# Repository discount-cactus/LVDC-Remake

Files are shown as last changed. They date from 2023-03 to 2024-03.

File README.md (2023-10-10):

# LVDC-Remake
Goal: Build an equivalent of the flight computer to the Saturn V rocket from the 1960's.

From: October 9th, 2022 - Present

<em>DISCLAIMER: This repo does NOT include schematics, board layouts or fabrication files for any of the boards that make up the project. The purpose of this repo is to share a breif insight to the progress of the project. Some small pieces of the project are provided, but are merely for educational purposes.</em>

### Memory Element



The Memory Element is composed of the memory and circuitry that manages the memory structure itself and stores all data for the LVDC. The original memory element stored information in a 128x64x14 array of ferrite cores that were magnetized in a certain direction to store a 1 or 0. For this project, and due to the complexity of constructing such an array of tiny ferrite cores, an Arduino Mega Pro was used to emulate this array - which further led to several modifications to circuitry directly interacting with the would-be ferrite core array.

### Memory Control Element



The Memory Control Element acts as the bridge between the memory and the rest of the computer by taking in commands and other addressing signals to be sent to the memory element to read and write to/from the memory. During read instructions, the memory control element configures the memory element to be ready to be read from - and likewise during write instructions configures the memory element to be written to.

### Data Control Element



The Data control Element provides the main register responsible for transferring data to locations all over the computer.

### Program Control Element



The Program Control Element manages the starting and stopping of programs, conditioning memory address decoders to select instructions, selecting data and instruction memory sectors, selecting instruction addresses within memory sectors, storing and decoding op codes, interrupting programs to perform subroutines and generating HOP constants to resume programs. 

### Arithmetic Element / Multiply-Divide Element



The Arithmetic Element and the Multiply-Divide Element were combined into the same board given their similar functions. Together, they handle all mathematical computations on the computer. The arithmetic handles all addition and subtraction and similar operations while the multiply-divide element, given their complexity, are dedicated strictly to binary multiplication and division.

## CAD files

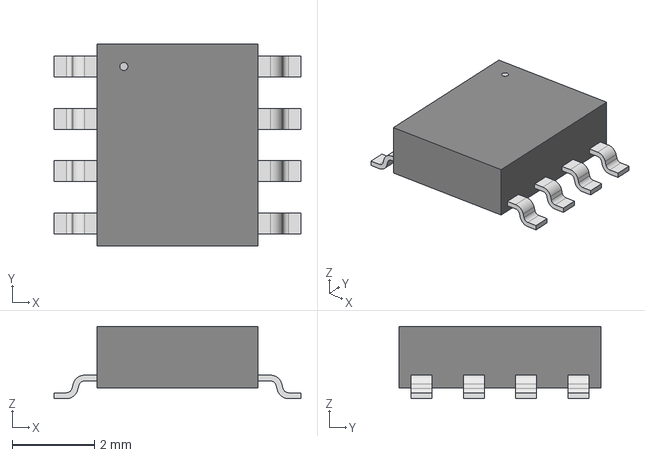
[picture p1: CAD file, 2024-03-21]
LVDC-Parts-Kicad/3dmodels/MCP2551_I_SN.step
5.99 x 4.90 x 1.75 mm

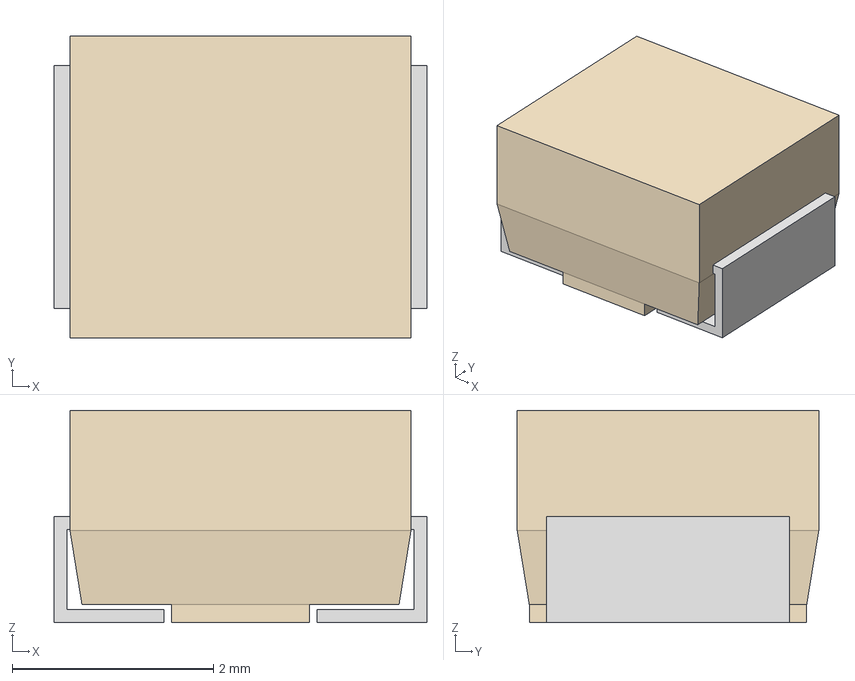
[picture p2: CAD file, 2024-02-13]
LVDC-Parts-Kicad/3dmodels/C_1411.step
3.71 x 3.00 x 2.11 mm

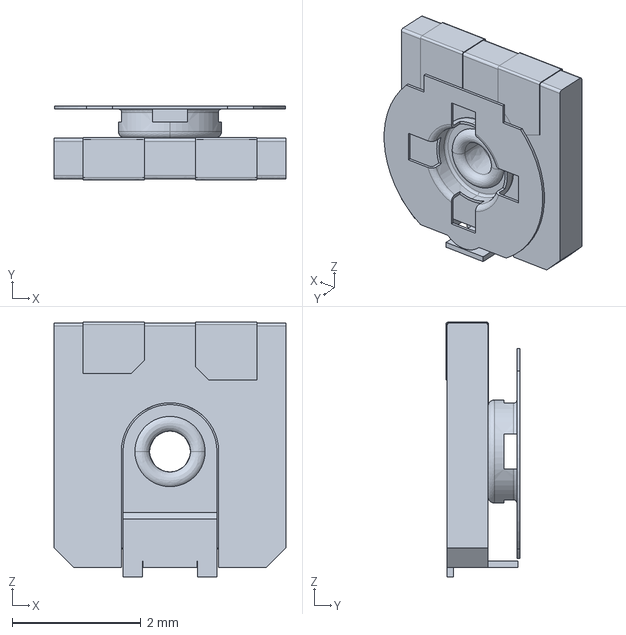
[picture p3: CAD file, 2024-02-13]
LVDC-Parts-Kicad/3dmodels/TC-33X-2.step
3.60 x 1.15 x 3.96 mm

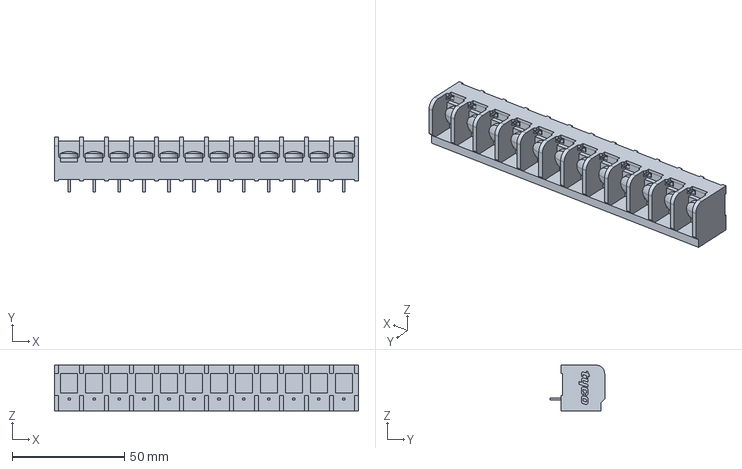
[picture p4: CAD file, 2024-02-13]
LVDC-Parts-Kicad/3dmodels/4-1437658-5.step
135.2 x 24.3 x 20.3 mm

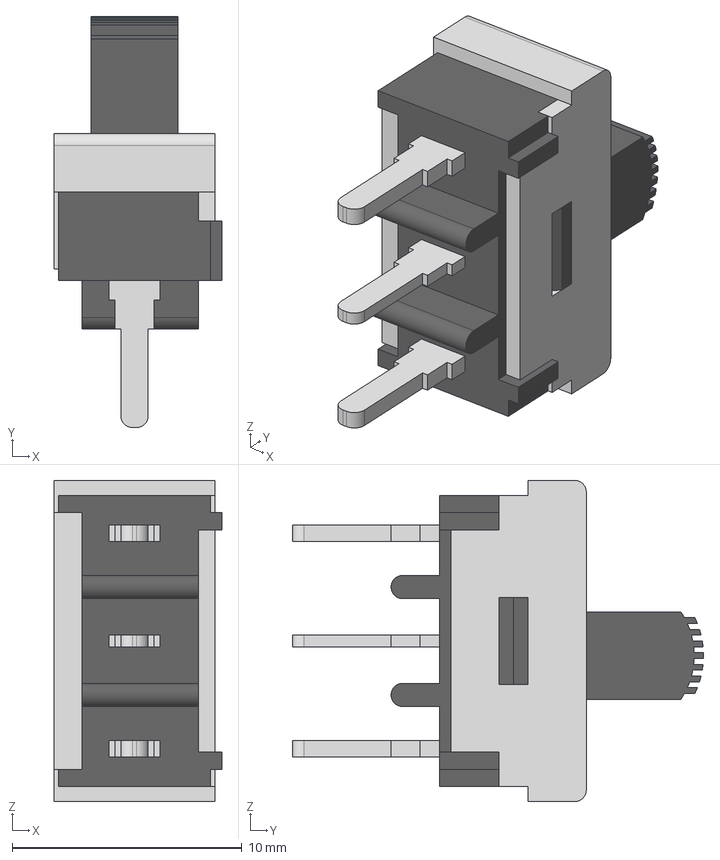
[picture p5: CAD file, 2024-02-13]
LVDC-Parts-Kicad/3dmodels/SPDT.step
7.32 x 17.9 x 14.0 mm
CS12ANW03-slide
CS12ANW03-term
CS12ANW03-top
CS12ANW03-body

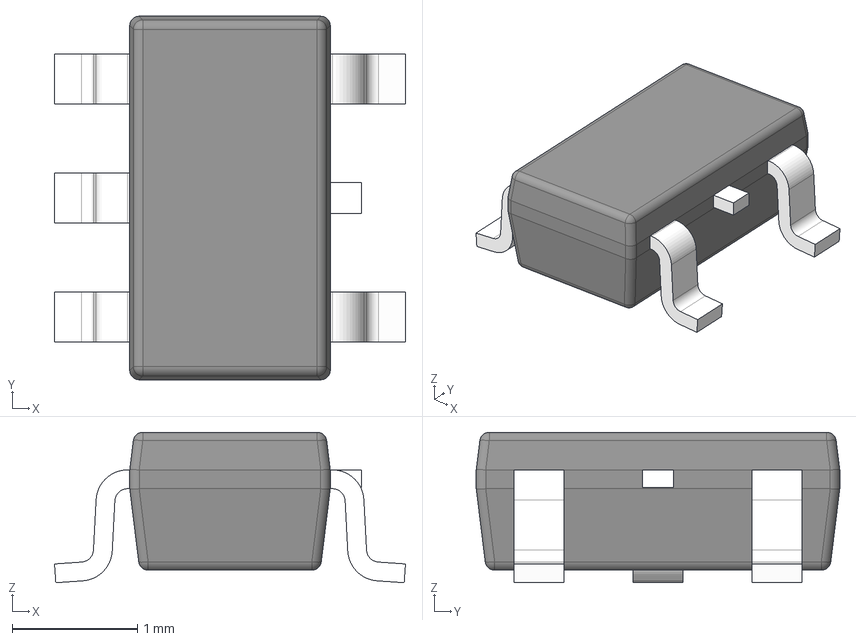
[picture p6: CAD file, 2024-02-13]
LVDC-Parts-Kicad/3dmodels/TLV170IDBVR.step
2.80 x 2.90 x 1.20 mm
BODY-SOT
LEAD-SOT x 5
LEAD-DUMMY

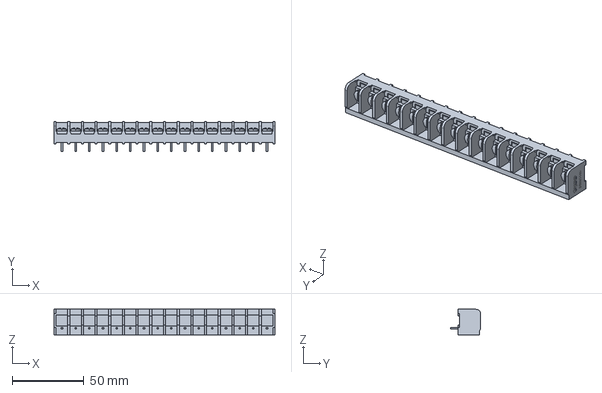
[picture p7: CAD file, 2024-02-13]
LVDC-Parts-Kicad/3dmodels/6PCV-16-006.step
153.9 x 21.0 x 17.8 mm

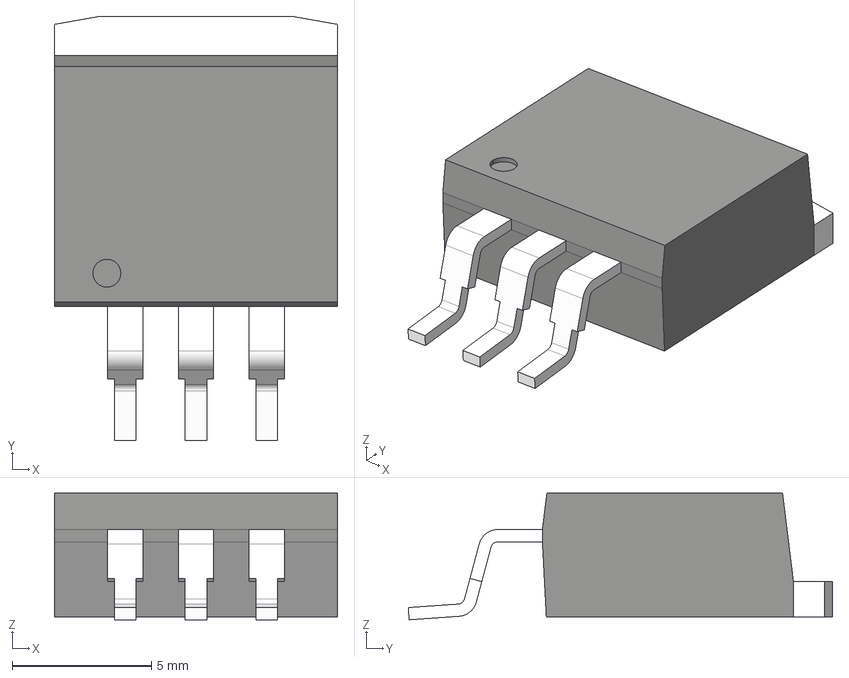
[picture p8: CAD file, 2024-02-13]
LVDC-Parts-Kicad/3dmodels/LM1084ISX-5-0-NOPB.step
10.2 x 15.2 x 4.54 mm
BODY-TO
HTSINK-TO263
LEAD-TO263 x 3

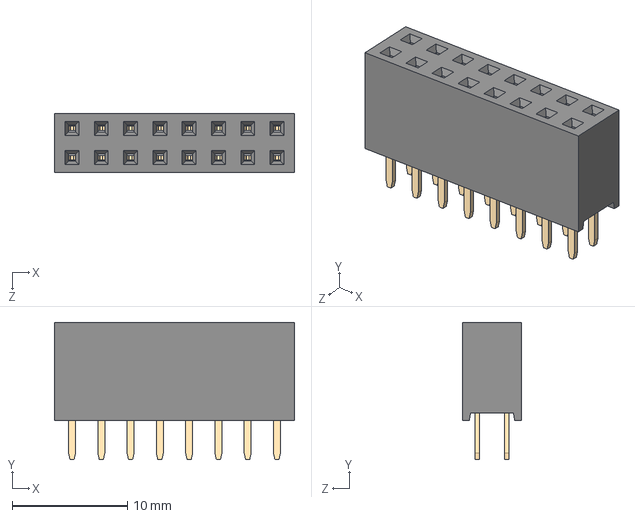
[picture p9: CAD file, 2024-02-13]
LVDC-Parts-Kicad/3dmodels/2x8.step
20.8 x 11.9 x 5.08 mm
2 row tin body_08
2 row tin pins x 8

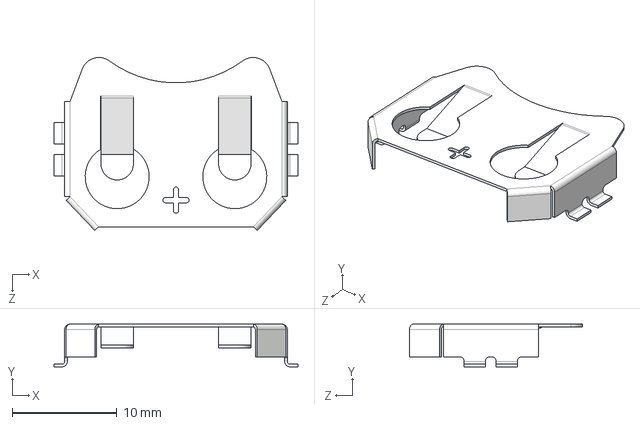
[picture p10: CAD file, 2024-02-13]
LVDC-Parts-Kicad/3dmodels/3034TR.step
23.2 x 4.06 x 16.5 mm

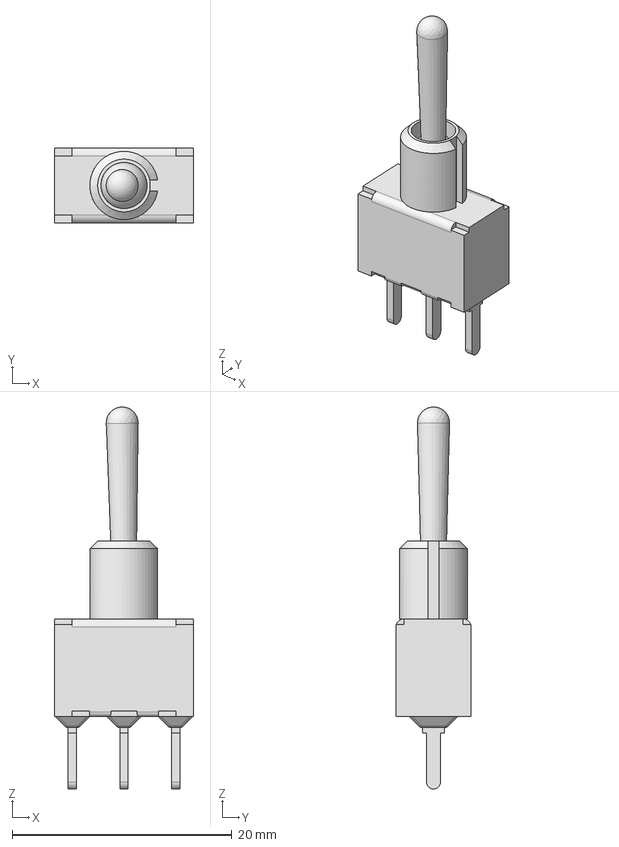
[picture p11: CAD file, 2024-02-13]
LVDC-Parts-Kicad/3dmodels/100SP1T1B4M2QE.step
12.7 x 6.86 x 34.8 mm

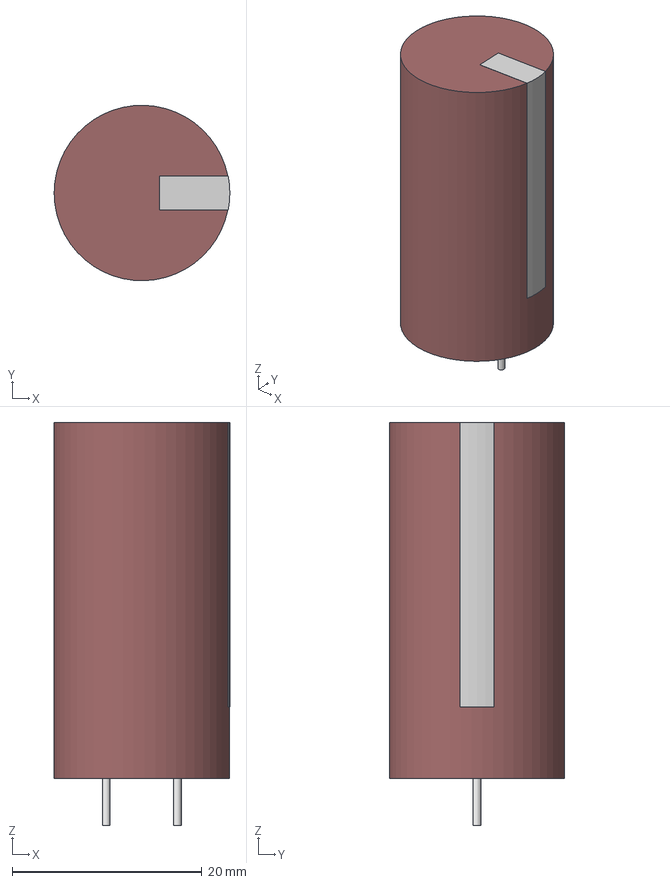
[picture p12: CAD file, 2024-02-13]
LVDC-Parts-Kicad/3dmodels/C_PKPZ.step
18.5 x 18.5 x 42.5 mm

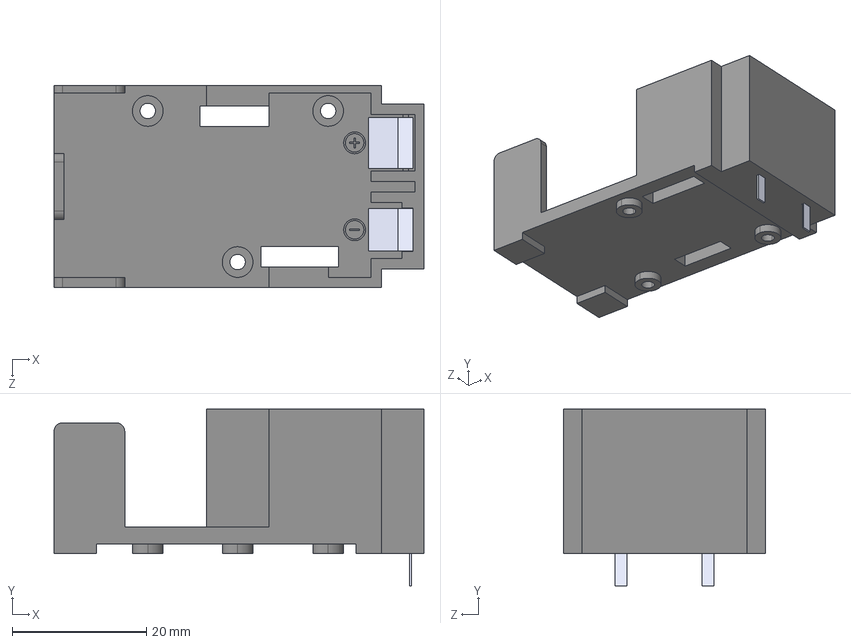
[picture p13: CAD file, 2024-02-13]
LVDC-Parts-Kicad/3dmodels/BC9VPC.step
55.1 x 26.3 x 30.1 mm

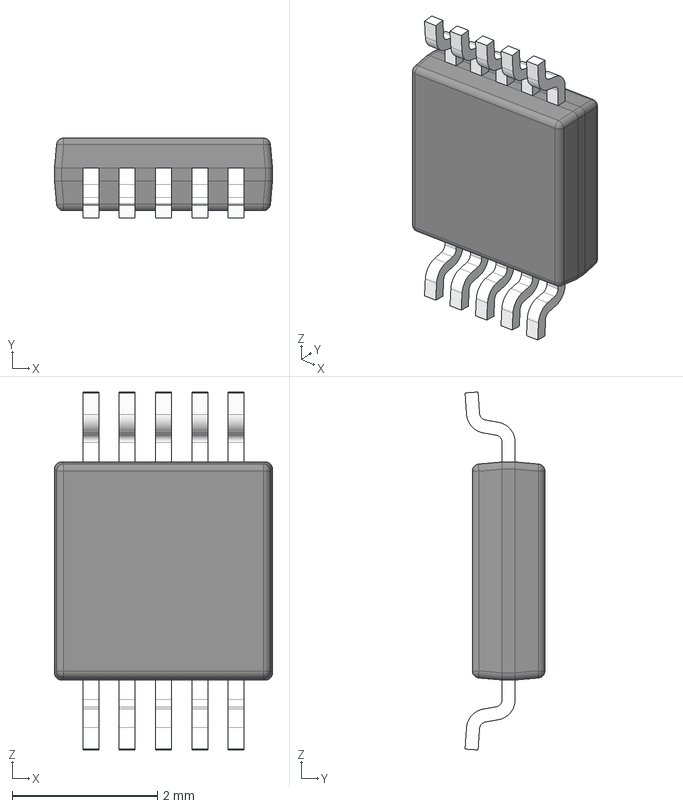
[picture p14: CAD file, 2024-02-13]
LVDC-Parts-Kicad/3dmodels/ADS1115IDGST.step
3.00 x 1.10 x 4.93 mm
BODY-SO
LEAD-SO x 10
PIN1-ID

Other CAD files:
LVDC-Parts-Kicad/3dmodels/LDL1117S50R.step
LVDC-Parts-Kicad/3dmodels/TS50P07G.step
LVDC-Parts-Kicad/3dmodels/DS3231M+TRL.step
LVDC-Parts-Kicad/3dmodels/1043P.step
LVDC-Parts-Kicad/3dmodels/10118193-0001LF.step
LVDC-Parts-Kicad/3dmodels/1017503.step
LVDC-Parts-Kicad/3dmodels/1101M2S3CQE2.step
LVDC-Parts-Kicad/3dmodels/14_DIP.step
LVDC-Parts-Kicad/3dmodels/16_DIP.step
LVDC-Parts-Kicad/3dmodels/1N4736A.step
LVDC-Parts-Kicad/3dmodels/1x10.step
LVDC-Parts-Kicad/3dmodels/1x13.igs
LVDC-Parts-Kicad/3dmodels/1x14.step
LVDC-Parts-Kicad/3dmodels/1x2.step
LVDC-Parts-Kicad/3dmodels/1x3.step
LVDC-Parts-Kicad/3dmodels/1x4.step
LVDC-Parts-Kicad/3dmodels/1x6.step
LVDC-Parts-Kicad/3dmodels/282858_4.step
LVDC-Parts-Kicad/3dmodels/2x12.step
LVDC-Parts-Kicad/3dmodels/2x13.step
LVDC-Parts-Kicad/3dmodels/2x14.step
LVDC-Parts-Kicad/3dmodels/2x16.STEP
LVDC-Parts-Kicad/3dmodels/2x18.step
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

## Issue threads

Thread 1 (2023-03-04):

Fix Input Interface Clocks

discount-cactus, 2023-03-04:
The input interface clocks were routed incorrectly during layout in Eagle and need to be reworked.

Actions:
- [x] Identify correct routing
- [x] Formulate plan to make all clocks functional with modifications to existing circuitry (_NOTE: 555 timers are in stock_)
- [x] Execute plan

discount-cactus, 2023-03-28:
Built replacement 555 timer that will be put onto the input interface tomorrow

discount-cactus, 2023-03-28:
The plan will be to remove clock circuitry and use the header pins on the input interface and will be bridged from the header pins to the perfboard with the replacement 555 timer.

discount-cactus, 2023-03-29:
Clock circuitry on input interface was removed to enable new clock circuitry to function. Incorrect wiring fried the 555 timer currently on the new 555 timer breakout board. The problem was fixed, leaving the only issue being the burnt 555 timer on the board. The plan now is to remove the burnt 555 timer, mount a new 555 timer on the opposite side, exposing the pins above, and jumping wires between the two 555 timers pins.

discount-cactus, 2023-03-30:
Finished the replacement timer circuit.

Closed 2023-03-30.

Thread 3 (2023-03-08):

Transistor Logic Trade Study

discount-cactus, 2023-03-08:
Test each type of single-stage amplifier and logic gate and log the results.

discount-cactus, 2023-04-20:
4/19/2023: After reviewing the task and ultimate goal of the study, the study is being moved to "Idea" indefinitely. The goal of the trade study was to understand the output voltage of transistor AND gates and OR gates but this is already known. The unknown was whether a resistor was NEEDED on the base for the circuit to work. The conclusion is "probably but maybe not" so (10kohm) resistors will be added to the base inputs of all transistor logic gates from now on to err on the side of caution.

discount-cactus, 2023-04-20:
Relevant pictures for optional future reference:
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

Closed 2023-04-22.

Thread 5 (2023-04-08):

Test Memory Module Stack

discount-cactus, 2023-04-08:
Use Timing Element R2

discount-cactus, 2023-04-13:
FRAM Chip Functionality.
- I2C connections are correct (4/9/2023)
- Adafruit uses 5V, Memory Modules use 3.3V. This should work as per Digikey website (4/9/2023)

https://learn.adafruit.com/adafruit-i2c-fram-breakout/wiring-and-test

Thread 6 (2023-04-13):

Input Interface Rev2

discount-cactus, 2023-04-13:
-Mechanical relays to physically cut power to 20V, 12V, 6V and 3V outputs
-Slow, medium, fast and manual clocks + 2 ports for external clocks
-Ports to gather data to send to python file
-Stiffener to prevent board warping
-Dock for espresso

discount-cactus, 2023-04-13:
4/12/2023:
Idea is as follows:
- Input Interface is a backplane with:
     - `Slots for five logic cards that plug in to the board, an onboard Arduino is used to select the logic cards`
     - `Slot for a single clock card to control the master clock`
     - `Plug-in for the Wall outlet-to-24V like on R1`
     - `Power is broken into 20V, 12V, 6V and 3V and distributed by distribution tiles - one for each board in the system and they stack vertically from the backplane like the memory module PCB's`
     - `Features a stiffener to prevent board warping like seen on R1`

discount-cactus, 2023-04-22:
4/21/2023:
- The input interface will feature two boards - an input/programming board and a power distribution board.
- Input Interface: Small board to mount up to five logic cards and a single clock card perpendicularly.
- Power Distribution: Built solely for distributing, managing and protecting the power going to each board that makes up the project.

discount-cactus, 2023-05-27:
5/26/2023: Issue closed due to decision on the architecture going forward.

Closed 2023-05-27.

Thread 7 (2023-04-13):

Latch Design Trade Study

discount-cactus, 2023-04-13:
The bistable storage latch on the LVDC project has been a persistent issue since the beginning so I am finally opening an issue specifically for tackling the design.

discount-cactus, 2023-04-13:
Design as of 3/30/23.

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

discount-cactus, 2023-04-13:
Schematic of latch per the NASA documentation:

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

discount-cactus, 2023-04-13:
Design as of 3/30/23:

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

discount-cactus, 2023-04-13:
Design as of 4/2/23:
The design was changed again and utilizes a CD4002BE quad 2-input OR gate to simplify the circuit from 12 components to 1.

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

discount-cactus, 2023-04-14:
4/13/2023: Initial testing was done with the design and the circuit looks promising, however the outputs are inverted due to the IC being a dual 4-input NOR gate instead of an OR gate.

discount-cactus, 2023-04-15:
4/15/2023: The previous comment is full of cap and the design with the CD4002BE dual 4-input NOR gate works. Progress on the LVDC will continue with this design.

Design:
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

00:
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

01:
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

10:
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

11:
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

Closed 2023-04-15.

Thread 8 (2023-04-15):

Zero-Drive Tratch Design Trade Study

discount-cactus, 2023-04-15:
Opening an issue to track development on the Zero-Drive Tratch circuit used in the Memory Control Element.

discount-cactus, 2023-04-15:
Schematic in LVDC documentation:
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

discount-cactus, 2023-08-10:
8-10-2023:
Multiple instantiations of the Zero-Drive Tratch appear in the Multiply-Divide Element - therefore the circuit design was revisited out of necessity. To accompany its absence from the Memory Control Element PCB in order to be integrated on a standalone PCB tile late, the final design will be placed on a tile as well for the Memory Control Element PCB.

Rev1 of the design yielded the following circuit.

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

discount-cactus, 2023-09-01:
9-1-2023:
The next iteration of the Zero-Drive Tratch saw the circuit simplified to two IC's - a 3-channel 3-input AND gate IC and a 4-channel 2-input NOR gate IC. This brought the part count down from 34 components to 2.

This reduction will save complexity, sources of error and cost per unit. With this iteration, the design was deemed optimized.

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

Closed 2023-09-01.

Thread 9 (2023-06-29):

Clean up MCE/DCE PCB Pads

discount-cactus, 2023-06-29:
After assembling the boards, many IC's have solder joints with adjacent pins and several IC's are misaligned with their footprints entirely. This will require a dedicated phase of cleanup to ensure the board works properly.

- [ ] Clean off all solder joints
- [ ] Re-align the misaligned footprints

discount-cactus, 2023-06-29:
6/29/2023: Cleaned the solder joints with solder wick.

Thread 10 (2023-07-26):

Harness Design Trade Study

discount-cactus, 2023-07-26:
Test multiple designs for harnesses and cabling for connecting the boards together

discount-cactus, 2023-08-10:
8-9-23:
A test print of a connector housing was made for a 2x20 connector. Upon visual inspection, the inner wall was snug and had little room for margins for solder joints so the wall will need to be extended. The length will also need to be extended another 2.54mm since the connectors dimensions can only fit a 2x19 connector.

discount-cactus, 2023-08-10:
8-10-23:
A follow-up test print with revisions (made by changing the scaling in Ultimaker Cura) was made and fit the 2x20 much better. The dimensions were 7mm x 53.8974mm x 5.0308mm (X/Y/Z)

discount-cactus, 2023-10-09:
10-9-23: It was concluded that the design CAN work, but the enclosure would have to be enlarged to ensure clearance for glue to enter the housing to hold and separate solder joints.

Closed 2023-10-09.

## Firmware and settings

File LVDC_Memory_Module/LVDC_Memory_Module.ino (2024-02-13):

//LVDC Memory Module
//Module to simulate a single memory module within the LVDC
#include <LVDC.h>
#include "Adafruit_FRAM_I2C.h"

#define FRAM_A1 4
#define FRAM_A2 5
#define SyllableSelect 6
#define MemoryModuleSelect 7
#define write_read 14
#define dataSig 15
#define ED_detect_Y 16
#define ED_detect_X 17

const int dataPin[14] = {A0,A1,A2,A3,A4,A5,A6,A7,A8,A9,A10,A11,A12,A13};
const int sectorSelect[4] = {36,37,38,39};

const int Lo_Y[3] = {22,23,24};
const int Hi_Y[3] = {25,26,27};
const int Lo_X[3] = {28,29,30};
const int Hi_X[4] = {32,33,34,35};

const int Lo_Y_answer[3] = {0,1,0};
const int Hi_Y_answer[3] = {0,1,0};
const int Lo_X_answer[3] = {0,1,0};
const int Hi_X_answer[4] = {0,0,1,0};

byte memory[64][64];
int syllable;
//int sector = 0;
int x_coordinate = 0;
int y_coordinate = 0;

int analogWriteVal = 255; // from 0-255

MemoryModule MM;
Adafruit_FRAM_I2C FRAM = Adafruit_FRAM_I2C(); //MB85RC256V FRAM chip

void setup() {
  Serial.begin(9600);
  while(!Serial){}
  FRAM.begin();                               //Default address is 0x50
  
  initialize_memory();                        //Initializes the memory
  //initialize_memory_with_random_data();
  
  for(int i=0; i < 14; i++){                  //Sets the address pins as inputs
    pinMode(dataPin[i],INPUT);
  }
  for(int i=0; i < 4; i++){                  //Sets the sector select pins as inputs
    pinMode(sectorSelect[i],INPUT);
  }
  for(int i=0; i < 3; i++){                   //Sets the y-coordinate select pins as inputs
    pinMode(Lo_Y[i],INPUT);
    pinMode(Hi_Y[i],INPUT);
    pinMode(Lo_X[i],INPUT);
  }
  for(int i=0; i < 4; i++){                   //Sets the x-coordinate select pins as inputs
    pinMode(Hi_X[i],INPUT);
  }
  pinMode(MemoryModuleSelect,INPUT);
  pinMode(SyllableSelect,INPUT);
  pinMode(write_read,INPUT);
  
  pinMode(ED_detect_Y,OUTPUT);
  pinMode(ED_detect_X,OUTPUT);
  pinMode(dataSig,OUTPUT);

  Serial.println("Entering loop"); delay(1000);
}

void loop() {
  //Functions only when the module is selected
  if (digitalRead(MemoryModuleSelect) == HIGH){

    update_data_location();
    
    if (digitalRead(write_read) == HIGH){         //Determines reading or writing, 0 = read, 1 = write
      readData(syllable, x_coordinate, y_coordinate);
    }else{
      writeData(syllable, x_coordinate, y_coordinate);
    }
  }
}





void initialize_memory(){
  for(int i=0; i < 64; i++){
    for(int ii=0; i < 64; ii++){
      memory[i][ii] = MM.location_empty; //0b00000000000000
    }
  }
}

/*void initialize_memory_with_random_data(){
  int num;
  for(int i=0; i < 64; i++){
    for(int ii=0; i < 64; ii++){
      byte tempData = 0b00000000000000;
      for(int i=0; i < 14; i++){
        num = random(0,10);
        if(num > 5){
          bitWrite(tempData,i,1);
        }else{
          bitWrite(tempData,i,0);
        }
      }
      memory[i][ii] = tempData;
    }
  }
}*/

void update_data_location(){
  int ii = 0;
  
  //Determines syllable
  if (digitalRead(SyllableSelect) == HIGH){
    syllable = 1;
  }else{
    syllable = 0;
  }
  
  //Determines sector
  /*sector = 0;
  ii = 0;
  for(int i=4; i > 0; i--){
    sector += sectorSelect[i] * pow(2,ii);
    ii++;
  }*/

  //Finds the xy coordinates
  int Lo_Y_coord = 0;
  for(int i=2; i >= 0; i--){
      Lo_Y_coord += Lo_X_answer[i] * pow(2,ii);
      ii++;
  }
  Serial.print("Lo Y: ");Serial.print(Lo_Y_coord); Serial.print("   ");

  int Hi_Y_coord = 0;
  ii = 0;
  for(int i=2; i >= 0; i--){
      Hi_Y_coord += Hi_Y_answer[i] * pow(2,ii);
      ii++;
  }
  Serial.print("Hi Y: ");Serial.print(Hi_Y_coord); Serial.print("   ");

  int Lo_X_coord = 0;
  ii = 0;
  for(int i=2; i >= 0; i--){
    Lo_X_coord += Lo_X_answer[i] * pow(2,ii);
    ii++;
  }
  Serial.print("Lo X: ");Serial.print(Lo_X_coord); Serial.print("   ");

  int Hi_X_coord = 0;
  ii = 0;
  for(int i=3; i >= 0; i--){
    Hi_X_coord += Hi_X_answer[i] * pow(2,ii);
    ii++;
  }
  Serial.print("Hi X: ");Serial.print(Hi_X_coord); Serial.print("   ");Serial.println("");

  if ((Lo_Y_coord == Hi_Y_coord) && (Lo_X_coord == Hi_X_coord)){
    //location = (Hi_Y_coord * 10) + Hi_X_coord;
    x_coordinate = 0;(Hi_X_coord * 10) + Lo_X_coord;
    y_coordinate = 0;(Hi_Y_coord * 10) + Lo_Y_coord;
    digitalWrite(dataSig,HIGH);
    Serial.println("Coordinates found");
  }else{
    if (Lo_Y_coord != Hi_Y_coord){
      pinMode(ED_detect_Y,HIGH);
      Serial.println("ERROR: Y coordinates not found.");
    }
    if (Lo_X_coord != Hi_X_coord){
      pinMode(ED_detect_X,HIGH);
      Serial.println("ERROR: X coordinates not found.");
    }
  }
}

//Stores data to memory
void writeData(int syl, int xCoord, int yCoord){
  for(int i=0; i < 14; i++){
    if(digitalRead(dataPin[i]) == HIGH){
      bitWrite(memory[xCoord][yCoord],i,1);
    }else{
      bitWrite(memory[xCoord][yCoord],i,0);
    }
  }
}

//Writes data to the board
void readData(int syl, int xCoord, int yCoord){
  for(int i=0; i < 14; i++){
    if(bitRead(memory[xCoord][yCoord],i) == 1){
      digitalWrite(dataPin[i],HIGH);
    }else{
      digitalWrite(dataPin[i],LOW);
    }
  }
}

void printData(int syl, int xCoord, int yCoord){
  Serial.println(memory[xCoord][yCoord]);
}

void data_sweep(){
  //Prints all data in the memory to serial port
  Serial.println("Data in Memory:");
  for(int i=0; i < 64; i++){
    for(int ii=0; i < 64; ii++){
      Serial.print(memory[i][ii]);Serial.print(", ");
    }
  }
}

void FRAM_write(int address, int FRAMdata){
  FRAM.write(address,FRAMdata);
}

uint8_t FRAM_read(int address){
  uint8_t value = FRAM.read(address);
  return value;
}

void FRAM_dump(){
  // dump the entire 32K of memory!
  uint8_t value;
  for (uint16_t a=0; a < 32768; a++) {
    value = FRAM.read(a);
    if ((a % 32) == 0) {
      Serial.print("\n 0x"); Serial.print(a, HEX); Serial.print(": ");
    }
    Serial.print("0x"); 
    if (value < 0x1) 
      Serial.print('0');
    Serial.print(value, HEX); Serial.print(" ");
  }
}

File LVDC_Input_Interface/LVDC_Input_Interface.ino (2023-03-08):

//LVDC Input Interface
//Used to send individual commands to the LVDC

#include "LVDC.h"

#define clockPin 9

int address[28] = {22,23,24,25,26,27,28,29,30,31,32,33,34,35,36,37,38,39,40,41,42,43,44,45,46,47,48,49};
int instruction[28] = {0,0,0,0,0,0,0,0,0,0,0,0,0,0,0,0,0,0,0,0,0,0,0,0,0,0,0,0};

int n = 0;

InputInterface II;

void setup(){
  II.setAddress(address); //Sets the pins as outputs
  II.writeToAddress(instruction); //Writes the output to the bus

  pinMode(clockPin,OUTPUT);
}

void loop(){
  //test_random_pins(); delay(1000);
  //test_sweep();
  //clock_pulse_2_048_MHZ();
  digitalWrite(clockPin,HIGH);
  delay(500);
  digitalWrite(clockPin,LOW);
  delay(500);

  //Gets data from desktop GUI when connected to laptop
  //THIS WILL BE ADDDED LATER, WILL NEED A PYTHON GUI
  //dataFromGUI = Serial.read(); instruction = dataFromGUI;
}





void test_random_pins(){
  for(int i=0; i < 28; i++){
    instruction[i] = random(0,2);
    if (instruction[i] == 1){
      digitalWrite(address[i],HIGH);
    }else{
      digitalWrite(address[i],LOW);
    }
  }
}

void test_sweep(){
  n++;
  if (n == 28){
    n = 0;
  }
  for(int i=0; i < 28; i++){
    if (i <= n){
      digitalWrite(address[i],HIGH);
    }else{
      digitalWrite(address[i],LOW);
    }
  }
  delay(100);
}

void clock_pulse_2_048_MHZ(){
  delayMicroseconds(1);
}

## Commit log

2022-11-21 Added Memory Module Arduino file
2022-11-21 Added LVDC Input Interface Arduino File
2022-12-17 Initial LVDC-Arduino Library commit
2023-02-05 Updated memory module code to support PCB
2023-03-08 Added Timing Element R2 Arduino code
2023-04-08 Added Kicad library parts
    [10118193-0001LF.step, 14_DIP.step, 16_DIP.step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]
2023-05-30 Updated KiCad part library
    [10118193-0001LF.step, 14_DIP.step, 16_DIP.step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]
2023-08-25 Updated KiCad parts library
    Update after finishing the Program Control Element PCB
    [1017503.step, 1N4736A.step, 1x10.step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]
2023-09-17 Updated Kicad parts library
    [CD4001BPWR.step, Fuse_15A.step]
2024-02-13 Update post-design of LVDC UPS
    [100SP1T1B4M2QE.step, 1043P.step, 1101M2S3CQE2.step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]
2024-03-21 Controller Updatess
    Updates to Kicad parts library after finishing the LVDC Controller.
    [MCP2551_I_SN.step]

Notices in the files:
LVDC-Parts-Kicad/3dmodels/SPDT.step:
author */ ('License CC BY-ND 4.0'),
